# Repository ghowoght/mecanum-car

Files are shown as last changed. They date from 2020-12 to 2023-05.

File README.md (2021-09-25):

## 软件流程

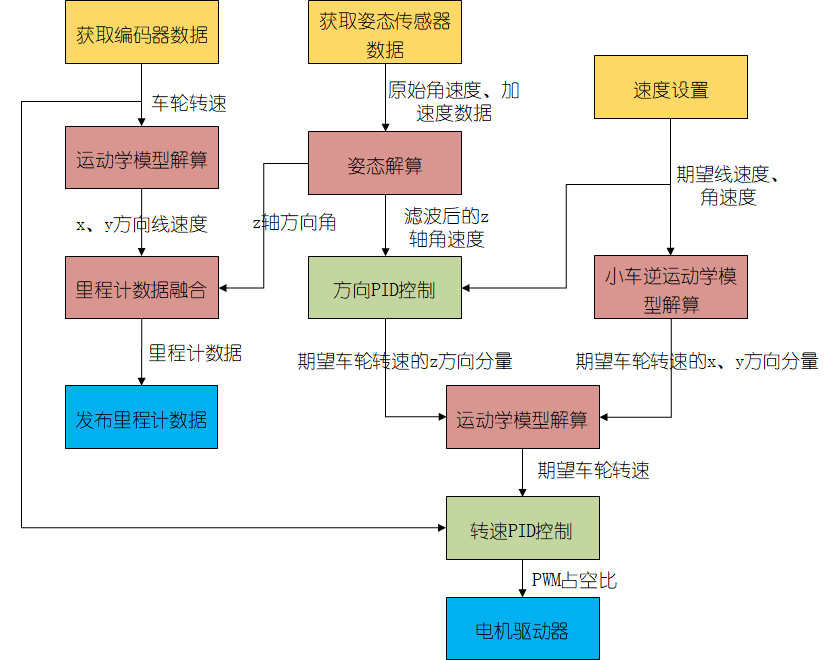
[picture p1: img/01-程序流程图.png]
01-程序流程图


## 硬件驱动

- ICM20602

  使用LL库的SPI函数获取原始的三轴加速度、三轴角速度数据

- 光电编码器

  使用STM32定时器的编码器模式进行读取

## BOM表

|                名称                |
| :--------------------------------: |
| STM32G474 Necleo / STM32G491Necleo |
|         ICM20602姿态传感器         |
|           75mm麦克纳姆轮           |
|  直流减速电机(带500线光电编码器)   |
|           A4950电机驱动            |

注：以上只列举了主要器件，还有部分器件未列出

## Todo List

- [x] 速度控制、方向控制
- [x] 添加Doxygen注释
- [ ] 使用EKF融合轮速计和IMU数据，获得更准确的里程计数据
- [ ] 将里程计数据加入位置控制
- [ ] 将通信协议更改为应答机制

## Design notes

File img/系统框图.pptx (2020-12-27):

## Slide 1

获取编码器数据

车轮转速

运动学模型解算

x、y方向线速度

获取姿态传感器数据

期望车轮转速的z方向分量

原始角速度、加速度数据

速度设置

z轴方向角

姿态解算

期望线速度、角速度

滤波后的z轴角速度

里程计数据融合

里程计数据

发布里程计数据

方向PID控制

小车逆运动学模型解算

期望车轮转速的x、y方向分量

期望车轮转速

运动学模型解算

转速PID控制

PWM占空比

电机驱动器

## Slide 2

获取语音数据

人机交互

获取图像数据

建图

语音识别

声源定位

自主建图

语义分割

自然语言处理
(理解语义)

生成动作指令

生成语义地图

获取图像数据

目标识别

抓取

自主定位

指令

路径规划

地图

导航

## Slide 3

语义建图

人机交互

动作指令

机器人
自主控制

目标检测

目标具体位置

语义地图与知识图谱
(包含目标大致位置)

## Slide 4

Realsense
D435i

深度图像
RGB图像

VINS-RGBD

机器人位姿

三维建图

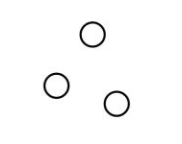
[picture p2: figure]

生成多个粒子
（每个粒子代表一个地图）

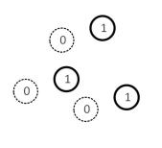
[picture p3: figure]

机器人移动产生位移

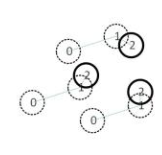
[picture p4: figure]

计算每个粒子的位移

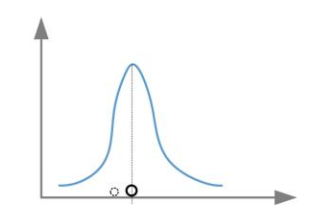
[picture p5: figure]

观察位移分布服从高斯分布

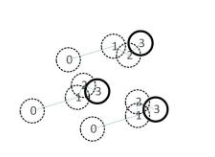
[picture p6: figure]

取均值和方差，并更新每个粒子的权重

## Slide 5

Realsense D435i

Color Image

RGBD Odometry

回环检测

RTAB-MAP

位姿
Pose

Depth
Image

Visual
Odometry

图优化

IMU data raw

点云拼接

三维地图

低通滤波

IMU data

无损卡尔曼滤波UKF

里程计
数据

机器人
速度

二维地图

电机编码器

车轮转速

麦克纳姆轮小车运动学解算

Rplidar
激光雷达

2D点云数据

GMapping

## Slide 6

获取语音数据

语音识别

自然语言处理
(理解语义)

生成动作指令

声源定位

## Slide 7

机器人
智能感知

学习openvino及相关算法

实现语义分割和知识图谱

实现目标检测

实现语音交互

机器人
自主控制

实现自主建图

实现语义建图

实现机器人自主定位与导航

实现
取物机器人

机器人
底层控制

根据需求完成机械结构设计

完成机器人
组装

实现移动底盘
精确控制

实现机械臂
精确控制

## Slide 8

测试环境

D区

C区

围栏

AI-Box

桌子

沙发

椅子

障碍物

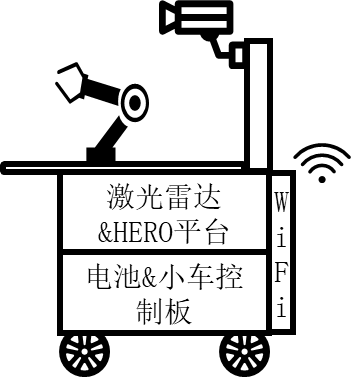
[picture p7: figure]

机器人

激光雷达&HERO平台

电池&小车控制板

WiFi

起点

A区

B区

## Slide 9

开始

录音

计时满3s？

语音活性检测

检测到语音？

语音识别

N

Y

N

Y

生成动作指令

结束

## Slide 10

开始

录音

计时满3s？

语音识别

N

Y

生成动作指令

结束

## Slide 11

获取图像

图像处理

感兴趣区域

角点检测

PNP问题求解

标定结果

目标坐标系与图像坐标系间位姿关系

目标在固定坐标系下的坐标

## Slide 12

P

P^(′)

P_1

P_2

O_1

O_2

C_1

C_2

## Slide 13

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
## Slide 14

电 机

电源管理系统

无线数传模块

上位机

UART

数据交换及通信系统

辅助控制核心TM4C123G

运动控制核心
TM4C123G

运动控制核心
TM4C123G

PID
控制器

姿态解算

数据融合及运动控制系统

UART

LC307
光流传感器

SPI

IMU

ICM20602
姿态传感器

UART

openMV
图像传感器

PWM3

电调

AK8975
磁力计

UART

SPL06
气压计

PWM1

电调

PWM2

电调

PWM4

电调

底层硬件驱动
系统

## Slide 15

反馈当前位置

位置PID
控制器

反馈当前速度

高度方向控制量

期望位置

期望速度
（位置环PID输出）

速度PID
控制器

控制
分配器

四轴

电
机

惯导融合

位置输出

期望角度
（速度环PID输出）

PWM

角度环PID控制器

反馈当前横滚角、俯仰角

期望角速度
（角度环PID输出）

角速度环PID控制器

反馈X、Y轴角速度

角速度环PID控制器

姿态解算

姿态输出

水平方向控制量

角度环PID控制器

反馈当前偏航角

期望角速度
（角度环PID输出）

期望偏航角

偏航方向
控制量

反馈Z轴角速度

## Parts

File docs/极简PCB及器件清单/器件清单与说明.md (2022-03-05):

扣除遥控器成本约为1000RMB，`Gerber_PCB_NucleoCar.zip`可直接在嘉立创进行打样

| 名称 | 链接 | 备注 |
| :---: | :---: | :---: |
| STM32G474/STM32G491 Nucleo开发板 | https://m.tb.cn/h.fNE8qJR?tk=XjY32fTJZWN | 173RMB x 1<br />STM32G491RE |
| 平衡小车之家**A4950**模块 | https://m.tb.cn/h.fmDkUjx?tk=urD92fTlZU4 | 25RMB x 2<br />单模块驱动两个电机 |
| 平衡小车之家**降压**模块 | https://m.tb.cn/h.fMxn4mm?tk=fBDA2fT9G6Q | 16.8RMB x 1<br />12V转5V 3.3V |
| 平衡小车之家**直流电机** | https://m.tb.cn/h.fnDeYEu?tk=g6322fTNEEK | 81.8RMB x 4<br />光电款 1:30 12V 带37支架 |
| 平衡小车之家**麦克纳姆轮** | https://m.tb.cn/h.fMxqcKn?tk=u6v72fTn6xe | 250RMB x 1<br />1组4个 75mm 不带键槽 6mm  |
| 平衡小车之家**12V电池** | https://m.tb.cn/h.fMxn4mm?tk=fBDA2fT9G6Q | 99RMB x 1<br />3S 3500mAh 带充电器 |
| 逐飞科技**ICM20602**模块 | https://m.tb.cn/h.fNE8aOR?tk=RHJb2fTpZu2 | 41.5RMB x 1 |
| SS12D06G5**拨动开关** | / | / |
| 富斯I6S 10通道**遥控器** | https://m.tb.cn/h.fMxJt6n?tk=2KrB2fTMq4b | 349RMB x 1<br />配iA10B接收机 |
| XH2.54 6P座子 | / | 4个 弯针 |

PCB预览：

PCB_PCB_NucleoCar_2022-03-05

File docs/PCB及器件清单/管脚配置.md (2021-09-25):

## 管脚配置

### 电机

| 电机1 | TIM1_CH1  | C0 |
| ----- | --- | ---- |
| | TIM1_CH1N | A11  |
| 电机2 | TIM1_CH2  | C1 |
| | TIM1_CH2N | B0 |
| 电机3 | TIM1_CH3  | A10  |
| | TIM1_CH3N | B1 |
| 电机4 | TIM1_CH4  | C3 |
| | TIM1_CH4N | C5 |

### 编码器（电机测速）

| 电机1 | A相  | TIM2_CH1  |  A0  |
| :---: | :--: | :---: | :--: |
| | B相  | TIM2_CH2  |  A1  |
| 电机2 | A相  | TIM3_CH1  |  C6  |
| | B相  | TIM3_CH2  |  A4  |
| 电机3 | A相  | TIM4_CH1  |  B6  |
| | B相  | TIM4_CH2  | A12  |
| 电机4 | A相  | TIM20_CH1 |  B2  |
| | B相  | TIM20_CH2 |  C2  |

### ICM20602

| 功能 | 管脚 |
| :--: | :---: |
| SPC  | B13（SCK）  |
| SDI  | B15（MOSI） |
| SDO  | B14（MISO） |
|  CS  | B11 |
| INT  | B12 |

### ADC(测电压)

|  功能 | 管脚 |
| :-----: | :--: |
| ADC_IN3 |  A6  |

### 遥控器接收机(PPM)

| 功能 | 管脚 |
| :---: | :--: |
| TIM17_CH1 |  A7  |

### 其他管脚

串口

| 功能 | 管脚 |
| :---: | :--: |
| UART4_RX  | C11  |
| UART4_TX  | C10  |
| USART3_RX |  B8  |
| USART3_TX | B10  |

PWM(可用于驱动机械臂)

| 功能 | 管脚 |
| :---: | :--: |
| TIM8_CH1 | A15  |
| TIM8_CH2 |  C7  |
| TIM8_CH3 |  C8  |
| TIM8_CH4 |  C9  |
| TIM5_CH2 | C12  |

###

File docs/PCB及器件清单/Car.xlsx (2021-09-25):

Comment | Description | Designator | Footprint | LibRef | Quantity | 购买连接
0.22u |  | C1, C3, C5, C9 | C_0805 | C_0805 | 4
C-100uF |  | C2, C4, C6, C10 | SMD-EC-F6.3 | C-100uF | 4 | SMD贴片铝电解电容器16V 25V 35V 50V 100UF 220UF 470UF 47UF-tmall.com天猫 (https://detail.tmall.com/item.htm?id=618566308237&spm=a1z09.2.0.0.7a6d2e8dQbhxix&_u=q33jkrfbe3fe)
0.1u |  | C7, C12 | C_0805 | C_0805 | 2
2.2u |  | C8 | C_0805 | C_0805 | 1
10n |  | C11 | C_0805 | C_0805 | 1
200n |  | C13 | C_0805 | C_0805 | 1
kong-2 |  | J1, J2 | HDR1X2 | kong-2 | 2 | https://detail.tmall.com/item.htm?id=622388441461&spm=a1z09.2.0.0.7a6d2e8dQbhxix&_u=q33jkrfb2275
motor |  | J3, J6, J7, J8 | XH2.54-6P | motor | 4
STM32G474_1 |  | J4 | HDR2*19 | STM32G474_1 | 1 | 2.54mm 排母 单排母单排母座 排针插座1*2P/3/4/5/6/9-40P (20个)-tmall.com天猫 (https://detail.tmall.com/item.htm?id=622082952245&spm=a1z09.2.0.0.7a6d2e8dQbhxix&_u=q33jkrfb0f17)
STM32G474_2 |  | J5 | HDR2*19 | STM32G474_2 | 1 | 2.54mm 排母 单排母单排母座 排针插座1*2P/3/4/5/6/9-40P (20个)-tmall.com天猫 (https://detail.tmall.com/item.htm?id=622082952245&spm=a1z09.2.0.0.7a6d2e8dQbhxix&_u=q33jkrfb0f17)
KEY |  | J9 | SS-12D10 | KEY | 1 | SS12D10G5柄高5MM 1P2T立式2档3脚 直/弯脚SS12D06拨动开关大电流-淘宝网 (taobao.com) (https://item.taobao.com/item.htm?spm=a1z09.2.0.0.7a6d2e8dQbhxix&id=601087935427&_u=q33jkrfb2e3d)
DC005 |  | J10 | DC-005 | DC005 | 1 | DC002 DC005直流电源插头插座公母接头3.5*1.1/1.3 5.5*2.1/2.5MM-淘宝网 (taobao.com) (https://item.taobao.com/item.htm?spm=a1z09.2.0.0.7a6d2e8dQbhxix&id=599535919103&_u=q33jkrfb9019)
H1*3 |  | J11 | HDR1X3 | H1*3 | 1 | XH2.54mm接插件 连接器端子 直脚/直针座 弯针座2P3P4P5P6P7P-14P-淘宝网 (taobao.com) (https://item.taobao.com/item.htm?spm=a1z09.2.0.0.7a6d2e8dQbhxix&id=602640026469&_u=q33jkrfb6ba0)
LED_0805 |  | LED1 | LED0805 | LED_0805 | 1
0.25 |  | R1, R2, R3, R4 | R_2512 | R-2512 | 4 | 2512贴片合金采样电阻2W 0.1R 0.12R 0.15 0.2 0.25 0.3 0.5R 1%-tmall.com天猫 (https://detail.tmall.com/item.htm?id=626580400225&spm=a1z09.2.0.0.7a6d2e8dQbhxix&_u=q33jkrfb8aac)
100 |  | R5 | R_0805 | R_0805 | 1
10k |  | R6, R8 | R_0805 | R_0805 | 2
100k |  | R7 | R_0805 | R_0805 | 1
A4950ELJTR-T |  | U1, U2, U3, U4 | SOIC-9N | A4950ELJTR-T | 4 | 全新 A4950ELJTR-T A4950T A4950 SOIC-8 DMOS PWM电机驱动器-tmall.com天猫 (https://detail.tmall.com/item.htm?id=620521558605&spm=a1z09.2.0.0.7a6d2e8dQbhxix&_u=q33jkrfbb549)
ICM-20602 | Accelerometer, Gyroscope, Temperature, 6 Axis Sensor IÂ²C, SPI Output | U5 | PQFN-16N | ICM-20602 | 1 | ICM-20600 I2600 20602 20608 I2608D 20645 IC2645 20649 IC2649-tmall.com天猫 (https://detail.tmall.com/item.htm?id=589393899579&spm=a1z09.2.0.0.7a6d2e8dQbhxix&_u=q33jkrfb2ec3)

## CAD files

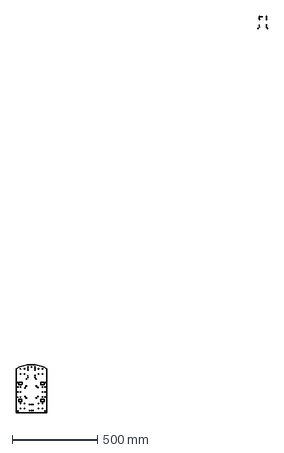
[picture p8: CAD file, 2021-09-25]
docs/固定板图纸/底板.dxf
1478.3 x 2327.3 mm

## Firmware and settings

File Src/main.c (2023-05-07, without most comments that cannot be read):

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
/* Includes ------------------------------------------------------------------*/
#include "main.h"

/* USER CODE BEGIN Includes */

#include "Scheduler.h"
#include "sys.h"
#include "icm20602.h"
#include "Sensor_Basic.h"
#include "stm32g4xx_hal.h"
#include "stdio.h"
#include "motor.h"
#include "dt.h"
#include "battery.h"

/* USER CODE END Includes */

ADC_HandleTypeDef hadc2;
DMA_HandleTypeDef hdma_adc2;

UART_HandleTypeDef hlpuart1;
UART_HandleTypeDef huart1;

TIM_HandleTypeDef htim1;
TIM_HandleTypeDef htim2;
TIM_HandleTypeDef htim3;
TIM_HandleTypeDef htim4;
TIM_HandleTypeDef htim20;

/* USER CODE BEGIN PV */

TIM_HandleTypeDef htim16;
TIM_HandleTypeDef htim17;
/* USER CODE END PV */

void SystemClock_Config(void);
static void MX_GPIO_Init(void);
static void MX_DMA_Init(void);
static void MX_LPUART1_UART_Init(void);
static void MX_USART1_UART_Init(void);
static void MX_TIM1_Init(void);
static void MX_TIM2_Init(void);
static void MX_TIM3_Init(void);
static void MX_TIM4_Init(void);
static void MX_TIM20_Init(void);
static void MX_ADC2_Init(void);
static void MX_SPI2_Init(void);
/* USER CODE BEGIN PFP */
static void MX_TIM16_Init(void);
static void MX_TIM17_Init(void);

/* USER CODE END PFP */

/* USER CODE BEGIN 0 */

	int fputc(int ch, FILE *f)
	{ 
		HAL_UART_Transmit(&hlpuart1, (uint8_t *)&ch, 1, 0xFFFF); 
		return ch; 
	} 

/* USER CODE END 0 */

/**
  * @brief  The application entry point.
  * @retval int
  */
int main(void)
{
  /* MCU Configuration--------------------------------------------------------*/

  /* Reset of all peripherals, Initializes the Flash interface and the Systick. */
  HAL_Init();

  /* Configure the system clock */
  SystemClock_Config();

  /* Initialize all configured peripherals */
  MX_GPIO_Init();
  MX_DMA_Init();
  MX_LPUART1_UART_Init();
  MX_USART1_UART_Init();
  MX_TIM1_Init();
  MX_TIM2_Init();
  MX_TIM3_Init();
  MX_TIM4_Init();
  MX_TIM20_Init();
  MX_ADC2_Init();
  MX_SPI2_Init();
  /* USER CODE BEGIN 2 */
	MX_TIM17_Init();
	
	TIM1->CCR1 = 500;
	TIM1->CCR2 = 500;
	TIM1->CCR3 = 500;
	TIM1->CCR4 = 500;
	

	HAL_TIM_PWM_Start(&htim1, TIM_CHANNEL_1);
	HAL_TIM_PWM_Start(&htim1, TIM_CHANNEL_2);
	HAL_TIM_PWM_Start(&htim1, TIM_CHANNEL_3);
	HAL_TIM_PWM_Start(&htim1, TIM_CHANNEL_4);
	HAL_TIMEx_PWMN_Start(&htim1, TIM_CHANNEL_1);
	HAL_TIMEx_PWMN_Start(&htim1, TIM_CHANNEL_2);
	HAL_TIMEx_PWMN_Start(&htim1, TIM_CHANNEL_3);
	HAL_TIMEx_PWMN_Start(&htim1, TIM_CHANNEL_4);
	

	HAL_TIM_Base_Start(&htim2);
	HAL_TIM_Base_Start(&htim3);
	HAL_TIM_Base_Start(&htim4);
	HAL_TIM_Base_Start(&htim20);
	HAL_TIM_Encoder_Start(&htim2,  TIM_CHANNEL_ALL);
	HAL_TIM_Encoder_Start(&htim3,  TIM_CHANNEL_ALL);
	HAL_TIM_Encoder_Start(&htim4,  TIM_CHANNEL_ALL);
	HAL_TIM_Encoder_Start(&htim20, TIM_CHANNEL_ALL);
	

	HAL_TIM_Base_Start(&htim17);
	HAL_TIM_IC_Start_IT(&htim17, TIM_CHANNEL_1);	

	HAL_Delay(50);
	

	ICM20602_Initialization();
	

	Kinematics_Init();


	PID_Init();
	

	Battery_Init();
  /* USER CODE END 2 */

  /* Infinite loop */
  /* USER CODE BEGIN WHILE */
	
  while (1)
  {		
		Main_Task();
    /* USER CODE END WHILE */

    /* USER CODE BEGIN 3 */
  }
  /* USER CODE END 3 */
}

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
/* USER CODE BEGIN 4 */
/**
  * @brief TIM16 Initialization Function
  * @param None
  * @retval None
  */
static void MX_TIM16_Init(void)
{

  TIM_IC_InitTypeDef sConfigIC = {0};

  htim16.Instance = TIM16;
  htim16.Init.Prescaler = 169;
  htim16.Init.CounterMode = TIM_COUNTERMODE_UP;
  htim16.Init.Period = 0xFFFF;
  htim16.Init.ClockDivision = TIM_CLOCKDIVISION_DIV1;
  htim16.Init.RepetitionCounter = 0;
  htim16.Init.AutoReloadPreload = TIM_AUTORELOAD_PRELOAD_DISABLE;
  if (HAL_TIM_Base_Init(&htim16) != HAL_OK)
  {
    Error_Handler();
  }
  if (HAL_TIM_IC_Init(&htim16) != HAL_OK)
  {
    Error_Handler();
  }
  sConfigIC.ICPolarity = TIM_INPUTCHANNELPOLARITY_RISING;
  sConfigIC.ICSelection = TIM_ICSELECTION_DIRECTTI;
  sConfigIC.ICPrescaler = TIM_ICPSC_DIV1;
  sConfigIC.ICFilter = 0;
  if (HAL_TIM_IC_ConfigChannel(&htim16, &sConfigIC, TIM_CHANNEL_1) != HAL_OK)
  {
    Error_Handler();
  }
}
/**
  * @brief TIM17 Initialization Function
  * @param None
  * @retval None
  */
static void MX_TIM17_Init(void)
{

  TIM_IC_InitTypeDef sConfigIC = {0};

  htim17.Instance = TIM17;
  htim17.Init.Prescaler = 169;
  htim17.Init.CounterMode = TIM_COUNTERMODE_UP;
  htim17.Init.Period = 65535;
  htim17.Init.ClockDivision = TIM_CLOCKDIVISION_DIV1;
  htim17.Init.RepetitionCounter = 0;
  htim17.Init.AutoReloadPreload = TIM_AUTORELOAD_PRELOAD_DISABLE;
  if (HAL_TIM_Base_Init(&htim17) != HAL_OK)
  {
    Error_Handler();
  }
  if (HAL_TIM_IC_Init(&htim17) != HAL_OK)
  {
    Error_Handler();
  }
  sConfigIC.ICPolarity = TIM_INPUTCHANNELPOLARITY_RISING;
  sConfigIC.ICSelection = TIM_ICSELECTION_DIRECTTI;
  sConfigIC.ICPrescaler = TIM_ICPSC_DIV1;
  sConfigIC.ICFilter = 0;
  if (HAL_TIM_IC_ConfigChannel(&htim17, &sConfigIC, TIM_CHANNEL_1) != HAL_OK)
  {
    Error_Handler();
  }
}



/* USER CODE END 4 */
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


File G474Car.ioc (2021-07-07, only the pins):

Mcu.UserName=STM32G474RETx
PA0.Signal=S_TIM2_CH1
PA1.Signal=S_TIM2_CH2
PA10.Signal=S_TIM1_CH3
PA11.Signal=TIM1_CH1N
PA12.Signal=S_TIM4_CH2
PA13.GPIO_Label=T_SWDIO
PA13.Signal=SYS_JTMS-SWDIO
PA14.GPIO_Label=T_SWCLK
PA14.Signal=SYS_JTCK-SWCLK
PA15.Signal=S_TIM8_CH1
PA2.GPIO_Label=LPUART1_TX [STLINKV3E_VCP_RX]
PA2.Signal=LPUART1_TX
PA3.GPIO_Label=LPUART1_RX [STLINKV3E_VCP_TX]
PA3.Signal=LPUART1_RX
PA4.Signal=S_TIM3_CH2
PA5.GPIO_Label=LD2 [green led]
PA5.Signal=GPIO_Output
PA6.Signal=ADC2_IN3
PB0.Signal=TIM1_CH2N
PB1.Signal=TIM1_CH3N
PB10.Signal=USART3_TX
PB11.Signal=GPIO_Output
PB12.Signal=GPXTI12
PB13.Signal=SPI2_SCK
PB14.Signal=SPI2_MISO
PB15.Signal=SPI2_MOSI
PB2.Signal=TIM20_CH1
PB3.GPIO_Label=T_SWO
PB3.Signal=SYS_JTDO-SWO
PB6.Signal=S_TIM4_CH1
PB7.Signal=USART1_RX
PB8-BOOT0.Signal=USART3_RX
PC0.Signal=S_TIM1_CH1
PC1.Signal=S_TIM1_CH2
PC10.Signal=UART4_TX
PC11.Signal=UART4_RX
PC12.Signal=S_TIM5_CH2
PC13.GPIO_Label=B1 [blue push button]
PC13.Signal=GPXTI13
PC14-OSC32_IN.Signal=RCC_OSC32_IN
PC15-OSC32_OUT.Signal=RCC_OSC32_OUT
PC2.Signal=S_TIM20_CH2
PC3.Signal=S_TIM1_CH4
PC4.Signal=USART1_TX
PC5.Signal=TIM1_CH4N
PC6.Signal=S_TIM3_CH1
PC7.Signal=S_TIM8_CH2
PC8.Signal=S_TIM8_CH3
PC9.Signal=S_TIM8_CH4
PF0-OSC_IN.Signal=RCC_OSC_IN
PF1-OSC_OUT.Signal=RCC_OSC_OUT

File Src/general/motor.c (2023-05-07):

/**
 * @file motor.c
 * @brief 
 * @author Linfu Wei (ghowoght@qq.com)
 * @version 1.0
 * @date 2020-12-27
 * 
 * @copyright Copyright (c) 2020  WHU-EIS
 * 
 */
#include "main.h"
#include "stm32g4xx_hal.h"
#include "motor.h"
#include "math.h"
#include "stdio.h"
#include "Sensor_Basic.h"
#include "imu.h"

extern TIM_HandleTypeDef htim1;
extern TIM_HandleTypeDef htim2;
extern TIM_HandleTypeDef htim3;
extern TIM_HandleTypeDef htim4;
extern TIM_HandleTypeDef htim20;

enum
{
	FL = 0,
	FR,
	BL,
	BR
}WHEELS;

kinematics_st kinematics;
pid_st pid[4];
pid_st pid_yaw;

/**
 * @brief 限幅函数
 * @param  x                输入数据
 * @param  min              最小值
 * @param  max              最大值
 * @return float 
 */
float Get_MiMx(float x, float min, float max ) 
{
	return ((x) <= (min)) ? (min) : ( ((x) > (max))? (max) : (x) );
}

/**
 * @brief 运动学模型初始化
 */
void Kinematics_Init(void)
{
	kinematics.max_rpm_ 						= 330; 				// 空载转速330rpm
	kinematics.max_linear_vel_			= 1.3f;
	kinematics.max_angular_z_				= 3.14f;
	kinematics.wheels_x_distance_		= 0.17;
	kinematics.wheels_y_distance_		= 0.19;
	kinematics.pwm_res_							= 500;
	kinematics.wheel_circumference_	= 0.2356194;  //轮子周长
	kinematics.total_wheels_				= 4;
	
	kinematics.exp_vel.linear_x  = 0.0;
	kinematics.exp_vel.linear_y  = 0.0;
	kinematics.exp_vel.angular_z = 0.0;
	
	kinematics.odom.pose.x = 0;
	kinematics.odom.pose.y = 0;
}

/**
 * @brief PID参数初始化
 */
void PID_Init(void)
{
	// 电机速度PID参数初始化
	for(int i = 0; i < 4; i++)
	{
		pid[i].kp							= 0.0015;	
		pid[i].ki							= 0;	
		pid[i].kd							= 0.0001;	
		pid[i].err						= 0;	
		pid[i].err_last				= 0;	
		pid[i].err_inte				= 0;	
		pid[i].err_diff				= 0;	
		pid[i].expect					= 0;	
		pid[i].expect_last		= 0;	
		pid[i].feedback				= 0;	
		pid[i].feedback_last	= 0;	
		pid[i].out						= 0;	
	}
	// 方向PID参数初始化
	pid_yaw.kp							= 4;	
	pid_yaw.ki							= 0;	
	pid_yaw.kd							= 0.1;	
	pid_yaw.err							= 0;	
	pid_yaw.err_last				= 0;	
	pid_yaw.err_inte				= 0;	
	pid_yaw.err_diff				= 0;	
	pid_yaw.expect					= 0;	
	pid_yaw.expect_last			= 0;	
	pid_yaw.feedback				= 0;	
	pid_yaw.feedback_last		= 0;	
	pid_yaw.out							= 0;	
}

/**
 * @brief 读取编码器数据
 * @param  dT_us            读取时间间隔
 */
static int last_encoder[4] = {0};
static int curr_encoder[4] = {0};
static int encoder_incre[4] = {0};
void Encoder_Task(u32 dT_us)
{
	curr_encoder[0] = -(short)TIM2->CNT;	// FL 1
	curr_encoder[1] =  (short)TIM3->CNT; 	// FR 2 
	curr_encoder[2] = -(short)TIM4->CNT; 	// BL 3
	curr_encoder[3] =  (short)TIM20->CNT;	// BR 4 
	
	for(int i = 0; i < 4; i++){
		encoder_incre[i] = curr_encoder[i] - last_encoder[i];
		if(encoder_incre[i] > 10000){
			encoder_incre[i] -= 65535;
		}
		else if(encoder_incre[i] < -10000){
			encoder_incre[i] += 65535;
		}
		last_encoder[i] = curr_encoder[i];	
	}
	// printf("enc: %d %d %d %d\r\n", curr_encoder[0], curr_encoder[1], curr_encoder[2], curr_encoder[3]);
	// printf("inc: %d %d %d %d\r\n", encoder_incre[0], encoder_incre[1], encoder_incre[2], encoder_incre[3]);
	
	float dT_s = dT_us * 1e-6;
	kinematics.fb_wheel_rpm.motor_1 = encoder_incre[0] / 30000.0f / dT_s * 60.0f;
	kinematics.fb_wheel_rpm.motor_2 = encoder_incre[1] / 30000.0f / dT_s * 60.0f;
	kinematics.fb_wheel_rpm.motor_3 = encoder_incre[2] / 30000.0f / dT_s * 60.0f;
	kinematics.fb_wheel_rpm.motor_4 = encoder_incre[3] / 30000.0f / dT_s * 60.0f;
}

/**
 * @brief 设置速电机PWM输出
 */
void Set_PWM(void)
{	
	const int 	ZERO 						= 500; 		// 电机静止时的设置值
	const float HUNDRED_PERCENT = 500.0f;  // 电机满幅输出时的设置值
	
	TIM1->CCR1 =  kinematics.pwm.motor_1 * HUNDRED_PERCENT + ZERO;
	TIM1->CCR2 =  kinematics.pwm.motor_2 * HUNDRED_PERCENT + ZERO;
	TIM1->CCR3 =  kinematics.pwm.motor_3 * HUNDRED_PERCENT + ZERO;
	TIM1->CCR4 =  kinematics.pwm.motor_4 * HUNDRED_PERCENT + ZERO;
}

/**
 * @brief 电机控制任务
 * @param  dT_us            控制周期
 */
void Motor_Task(u32 dT_us)
{
	Encoder_Task(dT_us); 		// 获取编码器读数
	Exp_Speed_Cal(dT_us);  	// 计算期望速度
	Fb_Speed_Cal(dT_us); 		// 计算反馈速度
	
	// 左前轮PID控制
	PID_Controller(	dT_us,  													// 控制周期
									kinematics.exp_wheel_rpm.motor_1, // 期望值
									kinematics.fb_wheel_rpm.motor_1, 	// 反馈值
									&pid[FL], 												// PID参数
									0,																// 单次积分限幅
									0);																// 积分限幅
	pid[FL].out  = Get_MiMx(pid[FL].out, -1.0, 1.0); 	// 输出限幅
	
	// 右前轮PID控制
	PID_Controller(	dT_us,  													// 控制周期
									kinematics.exp_wheel_rpm.motor_2, // 期望值
									kinematics.fb_wheel_rpm.motor_2, 	// 反馈值
									&pid[FR], 												// PID参数
									0,																// 单次积分限幅
									0);																// 积分限幅
	pid[FR].out  = Get_MiMx(pid[FR].out, -1.0, 1.0); 	// 输出限幅
	
	// 左后轮PID控制
	PID_Controller(	dT_us,  													// 控制周期
									kinematics.exp_wheel_rpm.motor_3, // 期望值
									kinematics.fb_wheel_rpm.motor_3, 	// 反馈值
									&pid[BL], 												// PID参数
									0,																// 单次积分限幅
									0);																// 积分限幅
	pid[BL].out  = Get_MiMx(pid[BL].out, -1.0, 1.0); 	// 输出限幅
	
	// 右后轮PID控制
	PID_Controller(	dT_us,  													// 控制周期
									kinematics.exp_wheel_rpm.motor_4, // 期望值
									kinematics.fb_wheel_rpm.motor_4, 	// 反馈值
									&pid[BR], 												// PID参数
									0,																// 单次积分限幅
									0);																// 积分限幅
	pid[BR].out  = Get_MiMx(pid[BR].out, -1.0, 1.0); 	// 输出限幅
	
	// 将PID计算结果转换为PWM占空比
	kinematics.pwm.motor_1 = -pid[FL].out;
	kinematics.pwm.motor_2 = -pid[FR].out;
	kinematics.pwm.motor_3 = -pid[BL].out;
	kinematics.pwm.motor_4 = -pid[BR].out;
	// 输出到电机
	Set_PWM();
}
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

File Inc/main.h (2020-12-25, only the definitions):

#define B1_Pin GPIO_PIN_13
#define B1_GPIO_Port GPIOC
#define B1_EXTI_IRQn EXTI15_10_IRQn
#define LPUART1_TX_Pin GPIO_PIN_2
#define LPUART1_TX_GPIO_Port GPIOA
#define LPUART1_RX_Pin GPIO_PIN_3
#define LPUART1_RX_GPIO_Port GPIOA
#define LD2_Pin GPIO_PIN_5
#define LD2_GPIO_Port GPIOA
#define T_SWDIO_Pin GPIO_PIN_13
#define T_SWDIO_GPIO_Port GPIOA
#define T_SWCLK_Pin GPIO_PIN_14
#define T_SWCLK_GPIO_Port GPIOA
#define T_SWO_Pin GPIO_PIN_3
#define T_SWO_GPIO_Port GPIOB

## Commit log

2020-12-25 创建项目
2020-12-25 修复PID原理上的BUG
2020-12-27 修复控制周期上的BUG，并添加注释
2020-12-27 修改和删减注释
2020-12-27 添加LED控制程序
2020-12-27 修改注释
2020-12-27 更新README
2020-12-30 修改无线通信协议
2020-12-31 修改README
2021-07-07 更新程序
2021-07-08 更改电机对应管脚
2021-09-19 更改静止检测参数，并利用静止信息来校正陀螺仪
2021-09-19 修改遥控器控制参数
2021-09-19 删减IMU驱动程序
2021-09-19 修改小车管脚配置，修复静止时小车自旋的BUG
2021-09-25 添加硬件图纸
    [Car.PrjPcb, Car.xlsx, Car_2.0.PcbDoc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]
2021-11-11 更改里程计数据发送频率
2021-11-21 更换姿态解算程序
2021-11-26 精简程序结构
2021-12-06 修改一些不符合逻辑的地方
2022-03-05 上传简化版PCB文件和器件清单
2022-03-14 添加电池电压测量程序
2022-03-14 修改LED任务，低电压闪两次，正常闪三次
2022-03-14 修改遥控逻辑，将速度控制分为三档
2022-04-17 删除无用文件
2022-04-17 将编译器从v5改成v6
2022-04-17 修复将编译器改成v6后的bug
2022-04-17 修改电机配置，适配简化版底板
2023-05-07 更改遥控器接口, 由tim16改为tim17
2023-05-07 统一编码, gb2312->utf-8
2023-05-07 删减数据传输程序, 波特率设置为460800
2023-05-07 电机控制任务中获取编码器增量后不再清零定时器CNT
2023-05-07 在读取imu时同步获取odo增量, 打包发送到上位机
2023-05-07 bugfix: 编码器增量计算错误

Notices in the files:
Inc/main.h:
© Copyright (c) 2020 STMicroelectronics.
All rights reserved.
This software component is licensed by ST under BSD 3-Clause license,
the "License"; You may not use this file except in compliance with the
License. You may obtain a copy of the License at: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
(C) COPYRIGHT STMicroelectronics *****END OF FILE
